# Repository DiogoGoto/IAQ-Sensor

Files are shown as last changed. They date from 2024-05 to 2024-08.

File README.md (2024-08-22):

# Indoor Air Quality (IAQ) Sensor

## Project Description
Low-cost indoor air quality sensor, this sensor is capable of collecting various air quality parameters and sending this data to a database hosted by Microsoft Azure, where the data can be accessed by a website. This data is also broadcasted using Bluetooth and it can be collected using an app developed using MIT App Inventor, with this app, and multiple sensors, it is also possible to keep track of where an individual has been and collect the personal air quality. More info at [Project post](https://www.hackster.io/Diterragames/indoor-air-quality-sensors-iaq-27ae14#overview)

## Table of Contents
- [Project Description](#project-description)
- [Functionality](#functionality)
- [Components](#components)
- [Quick Setup](#quick-setup)
- [Libraries](#libraries)
- [Contact](#contact)

## Functionality
- Measures Temperature (Celsius)
- Measures Relative Humidity (%)
- Measures CO2 (PPM)
- Measures Pressure (hPa) 
- Measures VOCs (PPM)
- Measures PM 1.0, 2.5, 10 (ug/m3)
- Sends data through Bluetooth
- Sends data to an online database
- Website to visualize the data

## Components
- [ESP-32 S3 Reverse TFT Feather](https://learn.adafruit.com/esp32-s3-reverse-tft-feather/overview)
- [ESP-32 S2 TFT Feather](https://learn.adafruit.com/adafruit-esp32-s2-tft-feather/overview)
- [SCD 30](https://learn.adafruit.com/adafruit-scd30/overview)
- [PMSA0031](https://learn.adafruit.com/pmsa003i/overview)
- [BME688](https://learn.adafruit.com/adafruit-bme680-humidity-temperature-barometic-pressure-voc-gas/overview)
- [Stemma QT cable 100mm](https://www.adafruit.com/product/4210)
- [Lipo 1200mAh Battery](https://www.adafruit.com/product/258)

## Quick Setup
Start by cloning this repository into your machine
#### Case and Circuit
1. Print the enclosure files under CAD Files.
2. Solder the sensors to the perfboard.
3. Connect the components as shown in the schematic.
4. Put the components inside their cases.
#### Cloud
1. Create a resource
2. Create an Azure IoT device using symmetric key as authentication type.
3. Save the _Device ID_ and _Primary Key_.
4. Create a CosmosDB account.
5. Create a CosmosDB routing endpoint.
6. Install Python 3.9.
7. Inside the project folder, run the following command: pip install -r requirements.txt.
8. Open cosmosdb.py and add your endpoint, database name and container name.
9. Run server.py.
10. Open azure_client.html.
#### Communication Unit Code
1. Install the esp32 board manager on version 2.0.17 by Espressif.
2. Install the [libraries](#libraries) for the communication unit.
3. Copy the folder _Uofc_Iaq_Library_ located Communication Unit\iaqazure\lib into your Arduino Libraries folder.
4. Create a folder named _iaqwif_" in the Libraries folder, then copy the _IaqWifi.h_ from src folder, paste it into the new folder, and rename it to _iaqwifi.h_
5. Open Communication Unit\iaqazure\src\azure\iot_configs.h change the wifi and Microsoft Azure settings.
6. Open Communication Unit\iaqazure\iaqazure.ino and update the ID to match the ID in the sensor unit code.
7. Upload the Communication unit code to the ESP-32 **S2**.
#### Sensor Unit Code
1. Install the [libraries](#libraries) for the sensor unit.
2. Open the file iaq_sensor located in Sensor Unit\IAQ_Sensor_Unit_Code.
3. Make sure that _BLE_MODE_ = 2 and that each sensor has an unique _SENSOR_ID_.
4. Upload the Sensor unit code to the ESP-32 **S3**.
#### Mobile App
1. Import the project into [MIT App Inventor](https://ai2.appinventor.mit.edu/).
2. Export the apk or use the [MIT Companion App](https://play.google.com/store/apps/details?id=edu.mit.appinventor.aicompanion3) to open the app.
3. Allow any permission requests by the app.

More details on how to set up are available in this [post](https://www.hackster.io/Diterragames/indoor-air-quality-sensors-iaq-27ae14#overview) in hackster.io.

## Libraries
#### Sensor Unit Libraries
- SPI
- Wire
- Adafruit_Sensor
- Adafruit_GFX
- Adafruit_ST7789
- Adafruit_SCD30
- Adafruit_PM25AQI
- BME68x Library
- [Bosch BSEC 2](https://github.com/boschsensortec/Bosch-BSEC2-Library/tree/master)
- Hardware Serial
- BLE Device
- BLE Advertising
- Any dependencies for these libraries
#### Communication Unit Libraries
- Azure SDK for C	
- ArduinoJson  
- Any dependencies for these libraries

## Thanks
I want to thank Dr. Simon Li who sponsored us by providing the needed components and accompanied the entire progress of this project. Thanks to my partner, Dr. Sheng Li, for participating in this project and assisting me. Last but not least the University of Calgary Electrical Makerspace for supplying us with materials, and allowing us to use its spaces and equipment to bring this project to reality.

## Contact
diogo.goto@gmail.com

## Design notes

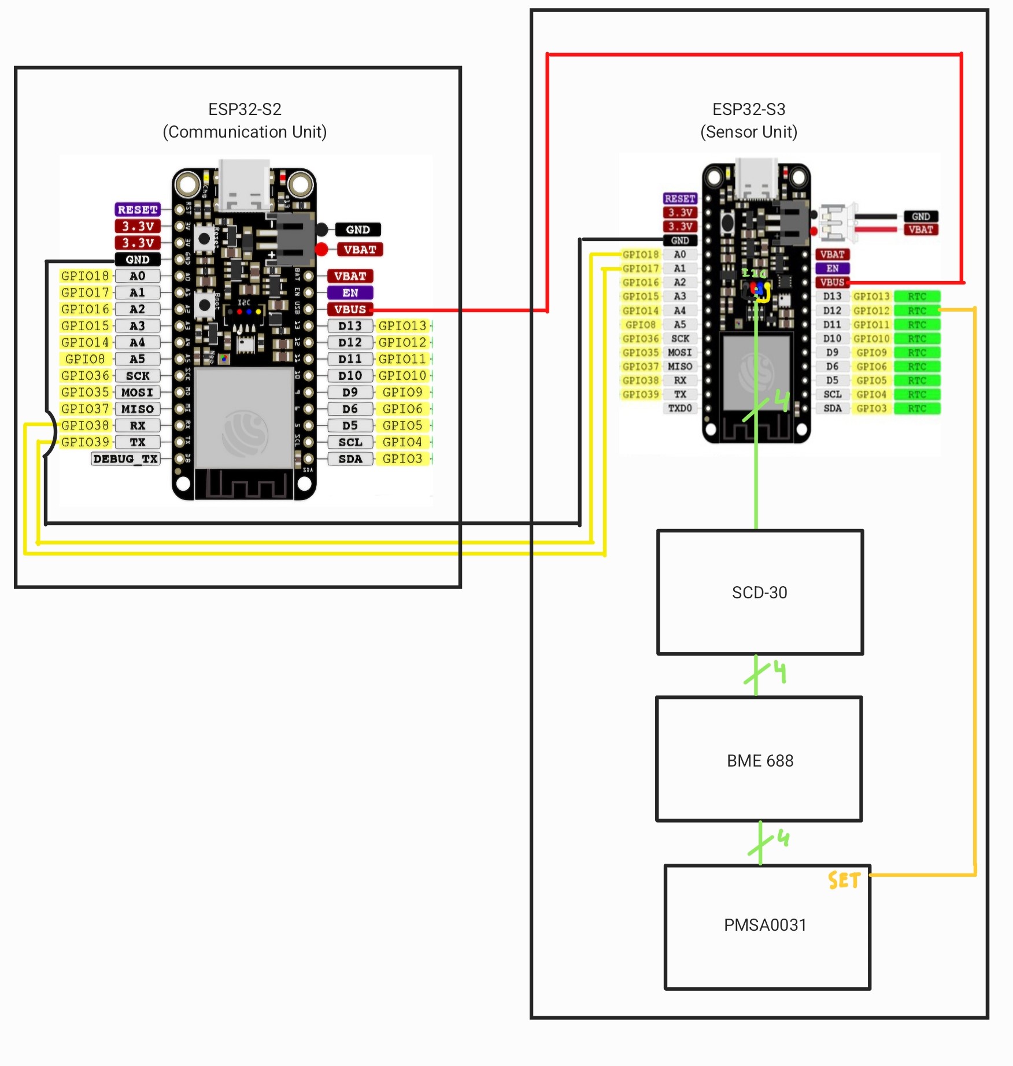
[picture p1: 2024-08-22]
Schematic.jpg

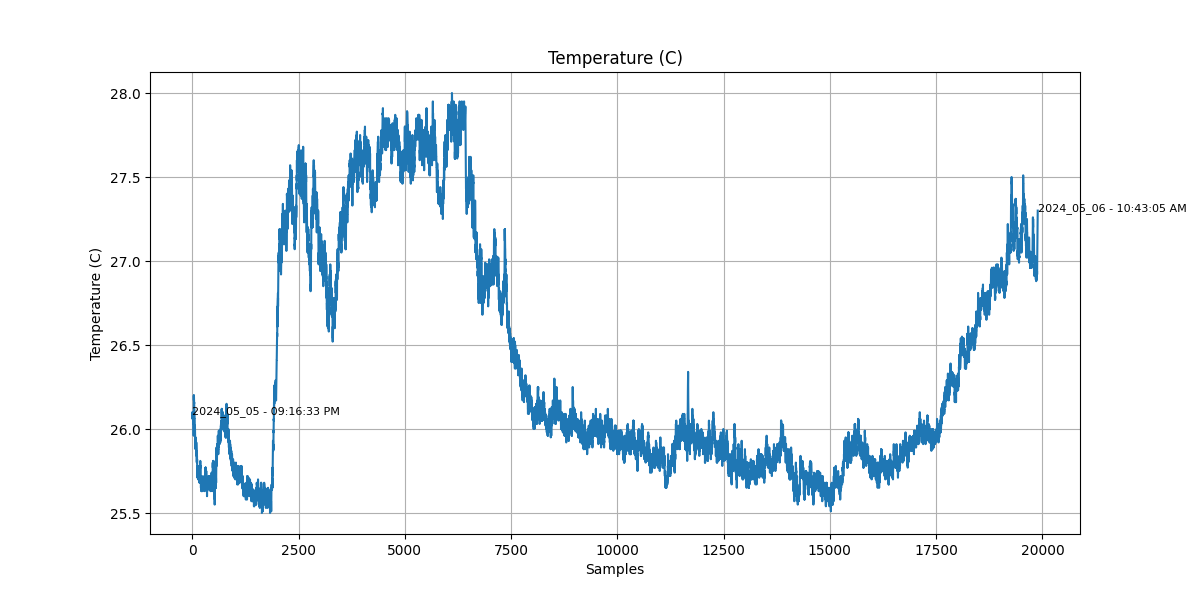
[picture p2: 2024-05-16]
Data_Logging/Graphs/Temp.png

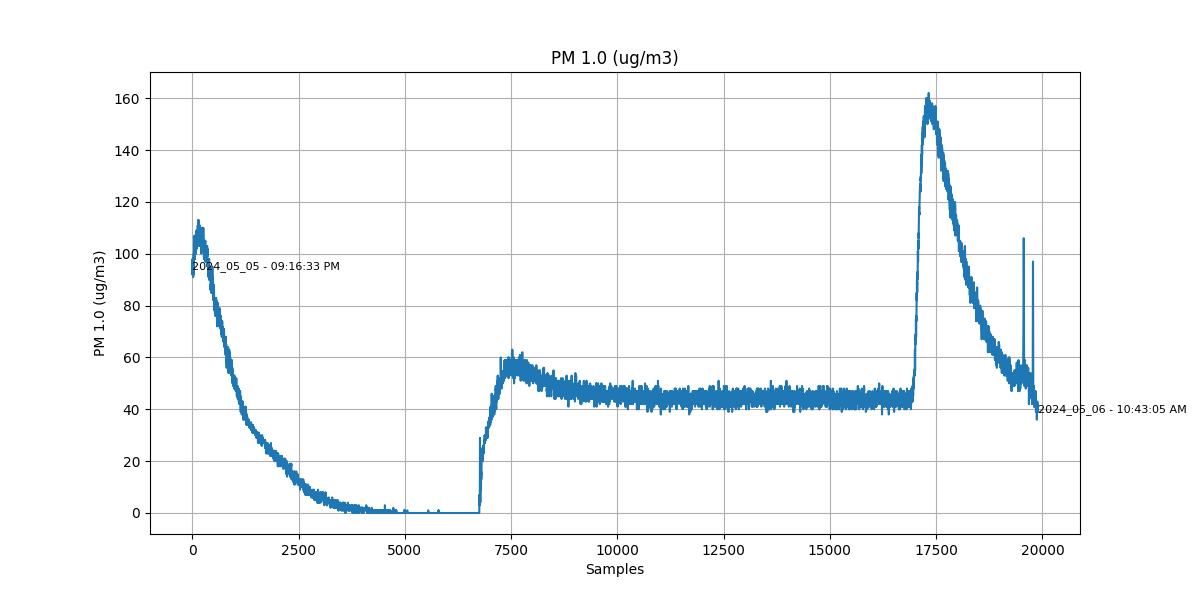
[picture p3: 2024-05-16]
Data_Logging/Graphs/PM1.png

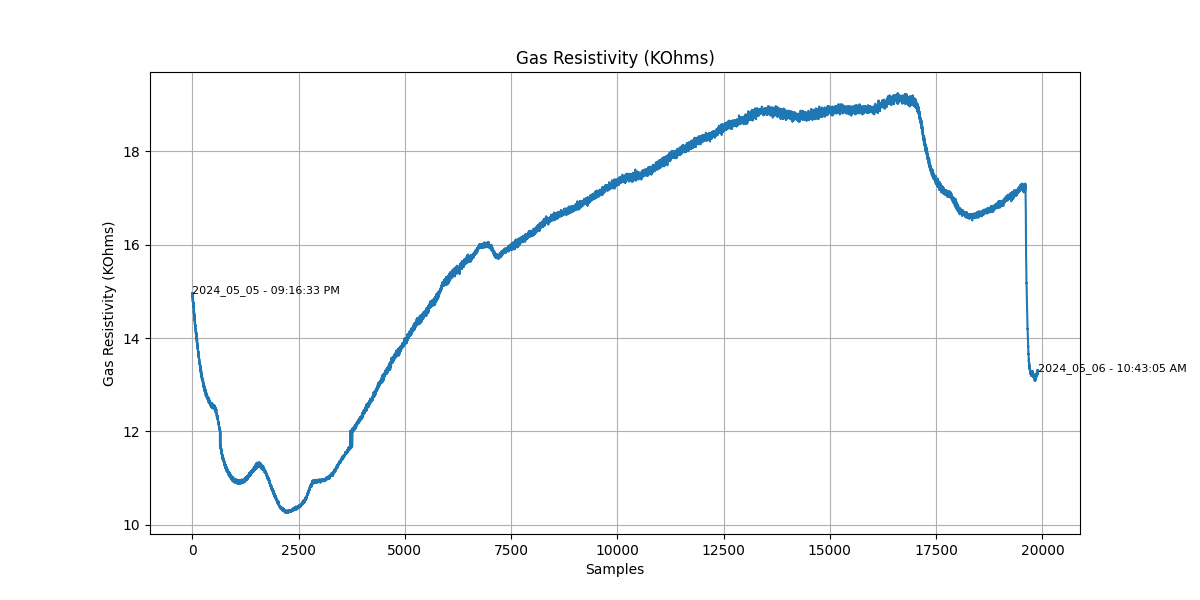
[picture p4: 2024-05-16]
Data_Logging/Graphs/Gas.png

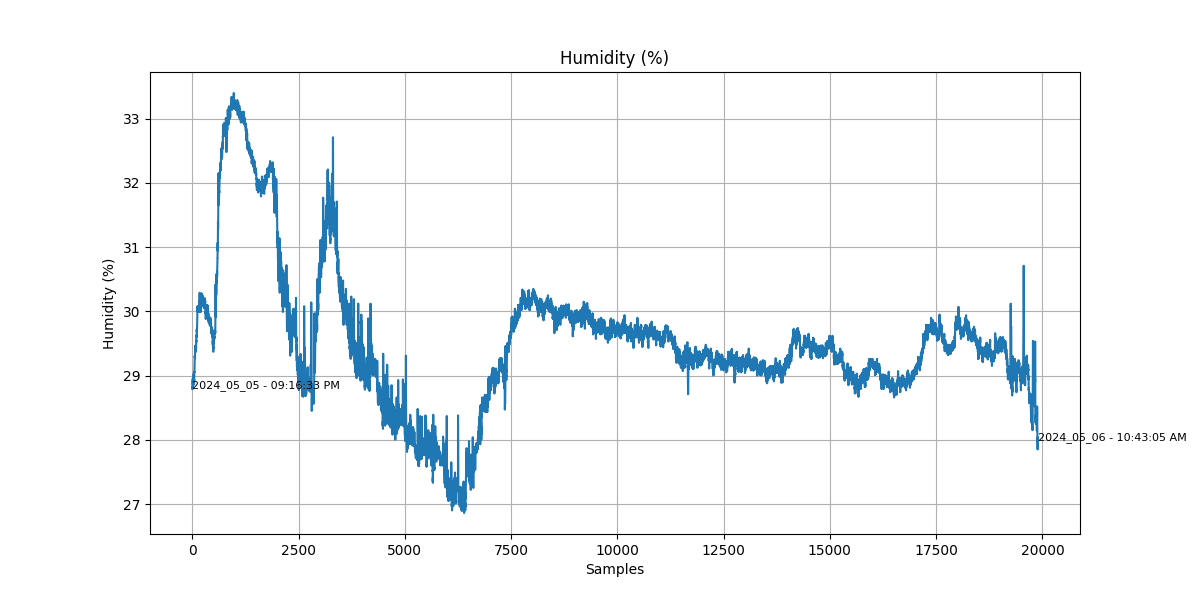
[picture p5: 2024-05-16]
Data_Logging/Graphs/RH.png

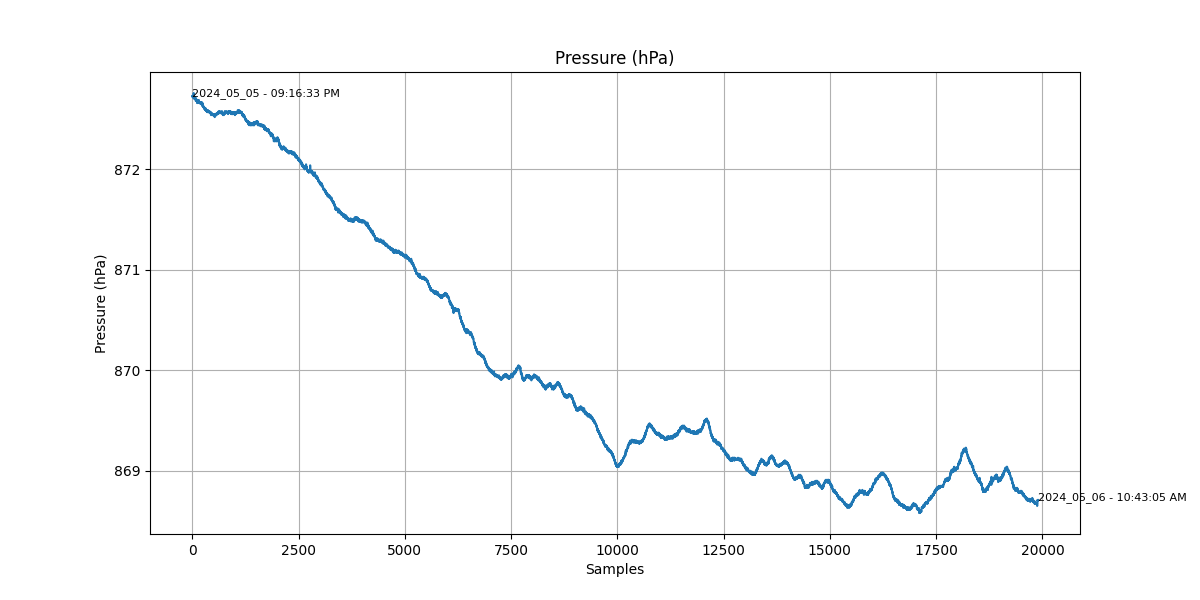
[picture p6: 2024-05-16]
Data_Logging/Graphs/Pres.png

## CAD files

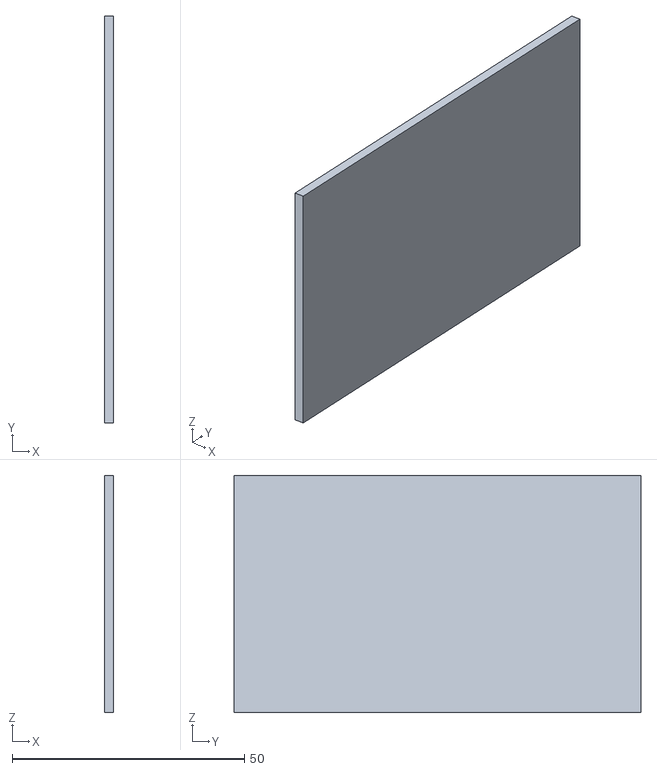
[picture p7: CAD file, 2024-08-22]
CAD Files/Cover Communication Unit.stl
2.00 x 87.5 x 51.0

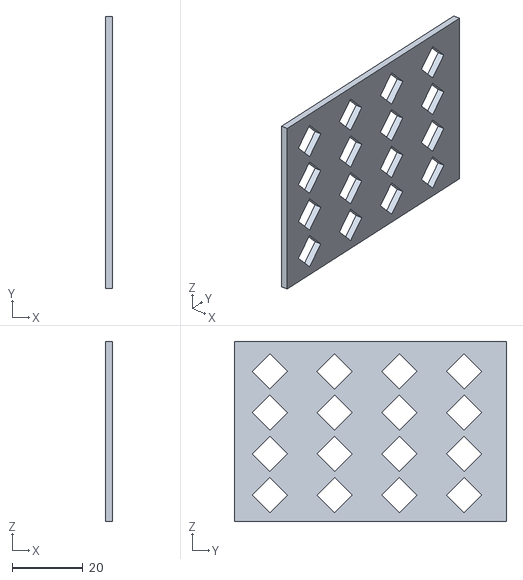
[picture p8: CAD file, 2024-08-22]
CAD Files/Cover Sensor Unit.stl
2.00 x 77.0 x 51.0

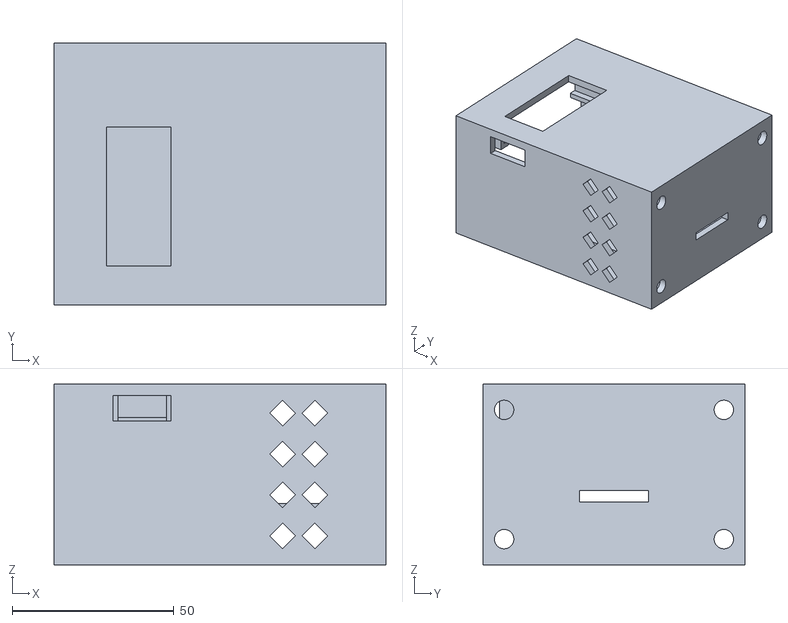
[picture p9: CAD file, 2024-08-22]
CAD Files/Case Sensor Unit.stl
102.8 x 81.0 x 56.0

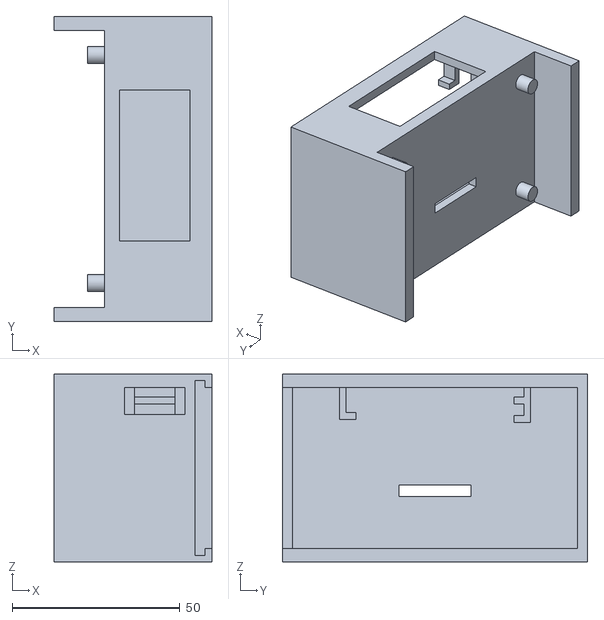
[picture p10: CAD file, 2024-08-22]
CAD Files/Case Communication Unit.stl
47.0 x 91.0 x 56.0

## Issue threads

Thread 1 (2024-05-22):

Design PCB

DiogoGoto, 2024-05-22:
- [ ] Design  and simulate Power Source Selector PCB
- [ ] Arrange Perf Board
- [ ] Design Interface with Dr. Sheng's Part

DiogoGoto, 2024-08-22:
Opted to use perf board and breakout boards, as designig a PCB was outside of the scope of the project

Closed 2024-08-22.

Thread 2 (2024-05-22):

Interface with Dr. Sheng's Part

DiogoGoto, 2024-05-22:
- [x] Decide Communication Protocol
- [x] Design physical connector
- [x] Decide formatting of the message (Modular Design)

DiogoGoto, 2024-08-22:
Implemented using Serial communication, the design of the connector was an 8-pin header, and the message was formatted to  "T=26.24,RH=28.83,P=886.46,CO2=496.52,VOC=0.58,PM1.0=0.00,PM2.5=0.00,PM10=0.00,[\n]". More info in post at hackster.io (link in README)

Closed 2024-08-22.

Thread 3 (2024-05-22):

Decide Size and Type of Battery

DiogoGoto, 2024-05-22:

DiogoGoto, 2024-08-22:
Opted for 1200mAh battery allowing for 8 hours of usage and connected directly into the ESP-32 S3 Battery Board. Check Schematic for more info.

Closed 2024-08-22.

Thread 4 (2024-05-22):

Check Power Consumption

DiogoGoto, 2024-05-22:
- [x] Check No Sleep mode
- [x] Check Modern Sleep
- [x] Check Light run mode
- [x] Check for Deep Sleep mode
- [x] Check Hibernate
-

DiogoGoto, 2024-08-22:
Opted for no sleep due to not being able to power off the BME680 and getting a reading right after being powered on. However, still turning off the PMSA0031 when not needed, and increasing the sampling interval to every minute, which allows a battery life of ~8 hours

Closed 2024-08-22.

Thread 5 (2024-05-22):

Implement Solar Panels

DiogoGoto, 2024-05-22:
- [x] Look For Solar Panels
- [ ] Create V x Light Intensity Curve, I x Light Intensity Curve
- [ ] Design Regulator Based on the Curves

DiogoGoto, 2024-08-22:
Requires a battery and solar panel too big to be worth

Closed 2024-08-22.

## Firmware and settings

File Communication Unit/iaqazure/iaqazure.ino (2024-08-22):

#define PART_IOT 1 // 0=sensor; 1=iot; Leave this line as is
#define PART_ID 1 // change here for each device
#define IAQ_AZURE_IOT_ID PART_ID 

#include <Wire.h>
#include <SPI.h>

#include <Adafruit_GFX.h>
#include <Adafruit_ST7789.h>
Adafruit_ST7789 tft = Adafruit_ST7789(TFT_CS, TFT_DC, TFT_RST);

// --- network;
#include "src/IaqWifi.h"
//#include "iaqaws.h"
#include "src/azure/azure.h"
#include "src/iaqnettime.h"

IaqWifi* iaqwifi = new IaqWifi();
IaqNettime iaqnettime = IaqNettime();
//IaqAws iaqaws = IaqAws();
Azure* iaqiot= new Azure();
#include <ArduinoJson.h>

// --- sensor modules;
#if PART_IOT ==1
#include <Adafruit_Sensor.h>
#include <IaqCo2.h>
//#include <IaqBme680.h>
//#include <iaqbme68x.h>
#include "src/iaqbsec.h"  // BME688
//#include <iaqSGP40.h>
#include <IaqPm.h>

IaqCo2 *iaqco2 = new IaqCo2();
IaqPm *iaqpm = new IaqPm();
IaqBsec* iaqbme = new IaqBsec();
//IaqBme68x* iaqbme = new IaqBme68x();
//IaqBme680 *iaqbme = new IaqBme680();
//IaqSGP40* iaqsgp = new IaqSGP40();
#endif

struct Iaqdata
{
  float sensorid = PART_ID;
  float temperature = 0.0;
  float humidity = 0.0;
  float pressure = 0.0;
  float gasResistance = 0.0;
  float gasiaq=0.0;
  float gasevoc=0.0;
  float gaseco2=0.0;
  float co2conc = 0.0;
  float pm2dot5 = 0.0;
  float pm1_0 = 0.0;
  float pm10 = 0.0;

  long long int timestamp = 0;
  long long int date = 0;

}iaqdata;
char jsonBuffer[512];

// --- other variables;
unsigned long last_time = millis();


void setup()
{
  delay(100);
  Serial.begin(115200);
  Serial1.begin(9600);
  Interface.begin(9600, SERIAL_8N1, RXD2, TXD2);
  delay(5000);

  Serial.println("--- iaq azure setup---");
  //iaqaws.setup();
  iaqiot->iaqwifi = iaqwifi;
  iaqiot->setup();
  iaqnettime.setup();

  setuptft();

#if PART_IOT==0
  iaqco2->setup();
  iaqpm->setup();
  iaqbme->setup();
  //bme_setup();
  //iaqsgp->setup();
#endif

}

bool isok=false;
int delaytime=300;
int iottime=50*1000/delaytime; // *100ms;
int iotcnt=iottime;   // for send data to iot server;
int readtime=3*1000/delaytime; // 2s;
int readcnt=readtime;
//int cnt=iotcnt-2000/delaytime;

unsigned char msgid=0;
bool isdata = false;

void loop() 
{
  isok = false;

  // if(iotcnt++>=iottime)
  // {
  //   iotcnt=0;
  //   //iaqaws.connectAWS();
  //   iaqwifi->connectToWiFi();
  //   //iaqiot->loop();
    
  //   if(iaqnettime.setup()){
  //     iaqdata.timestamp = iaqnettime.printLocalTime(); // Get the current timestamp
  //     iaqdata.date = iaqnettime.printLocalDate();
  //   }
  // }

#if PART_IOT==0
  iaqbme->read();

  if(readcnt++ >= readtime)
  {
    readcnt = 0;

    if(!iaqco2->read()) isok = false;
    iaqpm->read();
    //bme_read();

    //temperature = round((iaqco2->scd30.temperature -3.5)* 100) / 100;
    iaqdata.temperature = iaqbme->bme.temperature;
    iaqdata.humidity = iaqbme->bme.humidity;//round(iaqbme->bme.humidity * 100) / 100;  // %
    iaqdata.pressure = iaqbme->bme.pressure/100.0;//round((iaqbme->bme.pressure / 100.0) * 100) / 100; // Convert pressure to hPa
    iaqdata.gasResistance = iaqbme->bme.gas_resistance/1000.0;//round((iaqbme->bme.gas_resistance / 1000.0) * 100) / 100; // Convert gas resistance to kOhms
    iaqdata.gaseco2 = iaqbme->bme.eco2;
    iaqdata.gasevoc = iaqbme->bme.evoc;
    iaqdata.gasiaq = iaqbme->bme.iaq;

    iaqdata.co2conc = round(iaqco2->scd30.CO2 * 100) / 100;
    iaqdata.pm2dot5 = iaqpm->data.pm25_standard;
    iaqdata.pm1_0 = iaqpm->data.pm10_standard;
    iaqdata.pm10 = iaqpm->data.pm100_standard;

    sendSerial(&Serial);
    sendSerial(&Serial1);

    tft.fillScreen(ST77XX_BLACK); // Clear the TFT screen
    tft.setCursor(0, 0);
    tft.setTextSize(2);
    tft.setTextColor(ST77XX_GREEN);
    showTft();

    isdata = true;
  }
#else   // iot part;
  // receive data from serial port 1;
  if(receiveSensor(&Serial1)||receiveSensor(&Interface)) 
  {
    isdata = true;

    //sendSerial(&Serial);

    tft.fillScreen(ST77XX_BLACK); // Clear the TFT screen
    tft.setCursor(0, 0);
    tft.setTextSize(2);
    tft.setTextColor(ST77XX_GREEN);
    showTft();
    last_time = millis();
  }
  if(millis() - last_time > 65000){//Does not receive a message in the last 65 seconds
    tft.fillScreen(ST77XX_BLACK); // Clear the TFT screen
    tft.setCursor(0, 0);
    tft.setTextSize(3);
    tft.setTextColor(ST77XX_RED);
    tft.println("Disconnected");
    last_time = millis();
    Serial.print(millis()); Serial.print(last_time); Serial.println(millis() - last_time);
  }
#endif

  if(iotcnt++>=iottime && isdata)
  {
    isdata = false;

    iotcnt=0;
    //iaqaws.connectAWS();
    iaqwifi->connectToWiFi();
    //iaqiot->loop();
    
    if(iaqnettime.setup()){
      iaqnettime.printLocalTimeStr();
      //iaqdata.timestamp = iaqnettime.printLocalTime(); // Get the current timestamp
      //iaqdata.date = iaqnettime.printLocalDate();
    }
    
    int d = setMsg(iaqdata.sensorid, iaqdata.temperature, iaqdata.humidity, iaqdata.pressure, 
       iaqdata.gasevoc,//iaqdata.gasResistance,
       iaqdata.co2conc,iaqdata.pm2dot5,
       msgid++,iaqnettime.timestr);
    iaqiot->loop(jsonBuffer, d);
  
    // iaqaws.publishMessage(iaqdata.sensorid, iaqdata.temperature, iaqdata.humidity, iaqdata.pressure, 
    //   iaqdata.gasResistance,iaqdata.co2conc,iaqdata.pm2dot5,
    //   iaqdata.timestamp,iaqdata.date);
  }

  delay(delaytime);
}


int setMsg(float sensorid, float temperature, float humidity, float pressure, 
        float gasResistance, float co2conc, float pm2dot5, unsigned char msg_id, const char* timestr)//long long int timestamp, long long int date)
{
    //if(!isconnected) return;

    StaticJsonDocument<200> doc;
    doc["id"] = sensorid;
    doc["msgid"] = msg_id; // Add timestamp (in milliseconds)
    doc["datetime"] = timestr;
    doc["T"] = temperature;
    doc["RH"] = humidity;
    doc["P"] = pressure;
    doc["eVOC"] = gasResistance;
    doc["CO2"] = co2conc;
    doc["PM25"] = pm2dot5;
    
    return serializeJson(doc, jsonBuffer);

    // client->publish(AWS_IOT_PUBLISH_TOPIC, jsonBuffer);
    // //Serial.println(client->connected());
    // client->loop();
    // //Serial.println(client->connected());
}
bool receiveSensor(Stream* sp)
{
  bool isall=false;
  String str;
  String s;
  int d;
  while(true)
  {
    if(sp->available())
    {
      str = sp->readStringUntil(','); // terminal char is discarded;
      try
      {
        d = str.indexOf('=');
        s = str.substring(0,d+1);
        str = str.substring(d+1); 
        float f = str.toFloat();
        //Serial.printf("%s=%.2f\n",str,f);

        if (s.equals("T="))          {iaqdata.temperature=f; Serial.printf("t=%.2f,", iaqdata.temperature);}
        else if (s.equals("RH="))    {iaqdata.humidity=f; Serial.printf("rh=%.2f,", iaqdata.humidity);}
        else if (s.equals("P="))     {iaqdata.pressure=f; Serial.printf("co2=%.2f,", iaqdata.pressure);}
        else if (s.equals("CO2="))   {iaqdata.co2conc=f; Serial.printf("co2=%.2f,", iaqdata.co2conc);}
        else if (s.equals("VOC="))   {iaqdata.gasevoc=f; Serial.printf("voc=%.2f,", iaqdata.gasevoc);}
        else if (s.equals("PM1.0=")) {iaqdata.pm1_0=f; Serial.printf("pm1.0=%.2f,", iaqdata.pm1_0);}
        else if (s.equals("PM2.5=")) {iaqdata.pm2dot5=f; Serial.printf("pm2.5=%.2f,", iaqdata.pm2dot5);}
        else if (s.equals("PM10="))  {iaqdata.pm10=f; Serial.printf("pm10=%.2f,\n", iaqdata.pm10); isall = true;}

      }
      catch(...)
      {
        Serial.println("convert error.");
      }
    }
    else
    {
      break;
    }
  }
  return isall;
}
void sendSerial(Stream* sp)
{
  sp->printf("T=%.2f,", iaqdata.temperature);
  sp->printf("RH=%.2f,", iaqdata.humidity);
  sp->printf("P=%.2f,", iaqdata.pressure);
  sp->printf("CO2=%.2f,", iaqdata.co2conc);
  sp->printf("VOC=%.2f,", iaqdata.gasevoc);
  sp->printf("PM1.0=%.2f,", iaqdata.pm1_0);
  sp->printf("PM2.5=%.2f,", iaqdata.pm2dot5);
  sp->printf("PM10=%.2f,", iaqdata.pm10);
  sp->println();
  // sp->print("T: ");  Serial.print(iaqdata.temperature); Serial.print(" °C");
  // Serial.print(", RH: ");  Serial.print(iaqdata.humidity); Serial.print(" %");
  // Serial.print(", P: ");  Serial.print(iaqdata.humidity); Serial.print(" hPa");
  // Serial.print(", IAQ: ");  Serial.print(iaqdata.gasiaq);
  // Serial.print(", eCO2: "); Serial.print(iaqdata.gaseco2);
  // Serial.print(", eVOC: "); Serial.print(iaqdata.gasevoc);
  // Serial.print(", R: "); Serial.print(iaqdata.gasResistance); Serial.println(" kOhms: ");
}

void showTft()
{
  tft.fillScreen(ST77XX_BLACK); // Clear the TFT screen
  tft.setCursor(0, 0);
  tft.setTextSize(2);
  tft.setTextColor(ST77XX_GREEN);

  //tft.print("T    : ");  tft.print(temperature - 3.5);  tft.println(" DegreeC");
  tft.print("T    : ");  tft.print(iaqdata.temperature);  tft.println(" *C");
  tft.print("P    : ");  tft.print(iaqdata.pressure);  tft.println(" hPa");
  tft.print("RH   : ");  tft.print(iaqdata.humidity);  tft.println("%");
  
  tft.print("PM2.5: ");  tft.print(iaqdata.pm2dot5);  tft.println("  units");
  tft.print("CO2  : ");  tft.print(iaqdata.co2conc);  tft.println("  ppm");
  tft.print("eCO2 : ");  tft.print(iaqdata.gaseco2);   tft.println("  ppm");
  tft.print("eVOC : ");  tft.print(iaqdata.gasevoc);  tft.println("   ppm");
  tft.print("IAQ  : ");  tft.println(iaqdata.gasiaq);

  // tft.print("SGP  : ");  tft.print(iaqsgp->raw/1000.0); tft.println(" kOhms");
  // tft.print("Index: ");  tft.println(gasiaq);
  //tft.print("VOC = "); tft.print(gasvoc);  tft.println(" ppm");
  //tft.print("Altitude = ");
  //tft.print(iaqbme->bme.readAltitude(SEALEVELPRESSURE_HPA));
}


void setuptft(void) {
  Serial.print(F("Hello! Feather TFT Test"));

  // turn on backlite
  pinMode(TFT_BACKLITE, OUTPUT);
  digitalWrite(TFT_BACKLITE, HIGH);

  // turn on the TFT / I2C power supply
  pinMode(TFT_I2C_POWER, OUTPUT);
  digitalWrite(TFT_I2C_POWER, HIGH);
  delay(10);

  // initialize TFT
  tft.init(135, 240); // Init ST7789 240x135
  tft.setRotation(3);
  tft.fillScreen(ST77XX_BLACK);
  tft.fillScreen(ST77XX_BLACK);
  tft.setCursor(0,0);
  tft.setTextSize(2);
  tft.setTextColor(ST77XX_GREEN);
}

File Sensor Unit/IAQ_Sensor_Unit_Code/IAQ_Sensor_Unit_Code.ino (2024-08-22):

#include "iaq_sensor.h" 
/* Includes all relevant libries
*  Create all definitions
*  Declare all structures
*/
#if BLE_MODE == 1
  std::string SENSOR_NAME = "IAQ_Sensor_X"; //Change here for each sensor if running in BLE_MODE 1
#endif


// Function Prototypes
//----------------------------------------------
void displayInit(); // Initializes Built-in Display
void SCD30Init(); // Initializes CO2 Sensor
void PMInit(); // Initializes PM Sensor
void BMEInit(); //Initializes VOC and Pressure Sensor
void prepWrite(uint8_t size, uint16_t color); // Sets cursor at 0,0 configures color and font size
void intro(); //shows the intro to the sensor
void showTft(); // Print data on the display
void sendSerial();// Print data on Serial
void sendInterface(); //Send data to Dr. Sheng's Part through Serial
void sendBLE(); //Sends data to Mobile Devices

#if BLE_MODE == 1
  int getConnectedDevicesCount(); //return how many clients are connected
  int getFreeClientSlot(); //Finds a slot for to connect a new device
  int getClientSlotByConnId(uint16_t conn_id); //finds client by their connection ID
#endif
// ---------------------------------------------


//Modules Initializations
//----------------------------------------------
Adafruit_ST7789 tft = Adafruit_ST7789(TFT_CS, TFT_DC, TFT_RST); // Display
Adafruit_SCD30  scd30; //CO2 Sensor
Adafruit_PM25AQI aqi = Adafruit_PM25AQI(); //PM Sensor
PM25_AQI_Data pmsa0031; //Data for the PM sensor
IaqBsec* iaqbme = new IaqBsec();// Pressure and VOC Sensor
HardwareSerial Interface(1); //Data Interface 
//----------------------------------------------

iaqData data_package; //Data collected by the sensors 
String message = ""; //String to send the IAQ data to the Communication unit
unsigned long  last_time = millis(); // Timer collect the data every minute

//BLE Variables
#if BLE_MODE == 1
  BLEServer* pServer = NULL;
  BLECharacteristic* pCharacteristic = NULL;
  DEVICE ble_devices[MAX_CONNECTIONS]; //initializes all variables to connect to multiple devices


  class MyServerCallbacks: public BLEServerCallbacks {
      void onConnect(BLEServer* pServer, esp_ble_gatts_cb_param_t *param) {
        int idx = getFreeClientSlot();
        if (idx != -1) {
              ble_devices[idx].conn_id = param->connect.conn_id;
              ble_devices[idx].status = true;
              Serial.printf("Device connected, connection ID: %d\n", param->connect.conn_id);
          }
        // Continue advertising if not at max connections
          if (getConnectedDevicesCount() < MAX_CONNECTIONS) {
              pServer->startAdvertising();
              Serial.println("Continuing to advertise.");
          }
      };

      void onDisconnect(BLEServer* pServer, esp_ble_gatts_cb_param_t *param) {
          int idx = getClientSlotByConnId(param->disconnect.conn_id);
          if (idx != -1) {
              ble_devices[idx].conn_id = 0;
              ble_devices[idx].status = false;
              Serial.printf("Device disconnected, connection ID: %d\n", param->disconnect.conn_id);
          }
          if (getConnectedDevicesCount() < MAX_CONNECTIONS) {
              pServer->startAdvertising();
              Serial.println("Device disconnected, starting advertising.");
          }
          
      }

  };
#endif

#if BLE_MODE == 2
  BLEMultiAdvertising advert(1); // max number of advertisement data 
  unsigned int last_ble = 0;
  String sdata = "";
  int ble_i = 0;
#endif

// MAIN CODE
//========================================================================
void setup() {
  // Initilization sequence
  Serial.begin(115200);
  Serial.println("Time, Temp, RH, Pres, CO2, Gas, PM1, PM25, PM10");
  displayInit();
  intro();
  prepWrite(2,WHITE);
  SCD30Init();
  PMInit();
  BMEInit();
  delay(500);
  Interface.begin(9600, SERIAL_8N1, RXD2, TXD2);


  //BLE Setup
  #if BLE_MODE == 1
    BLEDevice::init(SENSOR_NAME); // Create the BLE Device
    pServer = BLEDevice::createServer(); // Create the BLE Server
    pServer->setCallbacks(new MyServerCallbacks());
    BLEService *pService = pServer->createService(SERVICE_UUID);// Create the BLE Service
    
    // Create a BLE Characteristic
    pCharacteristic = pService->createCharacteristic(
                        CHARACTERISTIC_UUID1,
                        BLECharacteristic::PROPERTY_READ   |
                        BLECharacteristic::PROPERTY_WRITE  |
                        BLECharacteristic::PROPERTY_NOTIFY |
                        BLECharacteristic::PROPERTY_INDICATE
                      );

    //pCharacteristic->setCallbacks(new MyCharacteristicCallbacks());
    pCharacteristic->addDescriptor(new BLE2902());// Create a BLE Descriptor
    pService->start(); // Start the service

    // Start advertising
    BLEAdvertising *pAdvertising = BLEDevice::getAdvertising();
    pAdvertising->addServiceUUID(SERVICE_UUID);
    pAdvertising->setScanResponse(false);
    pAdvertising->setMinPreferred(0x0);  // set value to 0x00 to not advertise this parameter
    pServer->getAdvertising()->start();
    Serial.println("Waiting a client connection to notify...");
  #endif


  #if BLE_MODE == 2
    BLEDevice::init("");

    advert.setAdvertisingParams(0, &legacy_adv_params);
    advert.setAdvertisingData(0, sizeof(legacy_adv_data), &legacy_adv_data[0]);
    advert.setScanRspData(0, sizeof(legacy_scan_rsp_data), &legacy_scan_rsp_data[0]);
    advert.setInstanceAddress(0, addr_legacy);
    advert.setDuration(0);
    delay(1000);
    advert.start(1, 0); // Start advertising with instance count 1 and infinite duration 
  #endif
}
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

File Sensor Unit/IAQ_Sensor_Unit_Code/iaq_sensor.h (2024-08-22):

#ifndef IAQ_SENSOR_H
#define IAQ_SENSOR_H
#define BLE_MODE 2
// Includes
//-----------------------------------------------------------------------
#include <SPI.h>
#include <Wire.h>
#include <Adafruit_Sensor.h>
#include <Adafruit_GFX.h>     // Core graphics library
#include "Adafruit_ST7789.h"  // Hardware-specific library for ST7789
#include <Adafruit_SCD30.h>   // CO2 Sensor
#include <Adafruit_PM25AQI.h> // PM Sensor
#include <HardwareSerial.h>   // Inteface with Dr. Sheng's Part
#include "iaqbsec.h"          // VOC & Pressure Sensor 
//Bluetooth Low Energy  Librabries
#include <BLEDevice.h> 
#if BLE_MODE == 1
  #include <BLEServer.h>
  #include <BLEUtils.h>
  #include <BLE2902.h>
#endif
#if BLE_MODE == 2
  #include <BLEAdvertising.h>
#endif
#include <vector>
//-----------------------------------------------------------------------

// Definitions
//-----------------------------------------------------------------------
#define PMSA_SET 12
#define RXD2 18
#define TXD2 17

/*
#define TFT_I2C_POWER 21
#define TFT_CS 7
#define TFT_DC 39
#define TFT_RST 40
#define TFT_BACKLITE 45 
*/

#define SAMPLING_PERIOD 60000 // 1 minutes sampling period
#define SEALEVELPRESSURE_HPA (1013.25) // Constant 
#define MAX_CONNECTIONS 4
//-----------------------------------------------------------------------

// Bluetooth UUIDs
#define SERVICE_UUID         "4fafc201-1fb5-459e-8fcc-c5c9c331914b"
#define CHARACTERISTIC_UUID1 "beb5483e-36e1-4688-b7f5-ea07361b26a8"
#define CHARACTERISTIC_UUID2 "77376cda-d67f-4c80-981e-7f7cd032c684"
#define CHARACTERISTIC_UUID3 "3ea2d89f-5e58-454f-82ad-6fe705428db2"
#define CHARACTERISTIC_UUID4 "a0ea85f6-86ef-427b-8743-446f01fc3421"



// Colors definitions
// Colors are represented by 16bits values
//-----------------------------------------------------------------------
#define BLACK 0x0000
#define WHITE 0xFFFF
#define RED 0xF800
#define GREEN 0x07E0
#define BLUE 0x001F
#define CYAN 0x07FF
#define MAGENTA 0xF81F
#define YELLOW 0xFFE0
#define ORANGE 0xFC00
//-----------------------------------------------------------------------

typedef struct IAQ_DATA
{
  float sensorid = 3;
  
  //SCD 30 Data
  float temperature = 0.0;
  float humidity = 0.0;
  float co2 = 0.0;

  //PMSA 0031 Data
  float pm1dot0 = 0.0;
  float pm2dot5 = 0.0;
  float pm10 = 0.0;

  //BME 688 Data
  float gasTemperature = 0.0;
  float gasPressure = 0.0;
  float gasHumidity = 0.0;
  float gasResistance = 0.0;
  float gasIaq=0.0;
  float gaseVoc=0.0;
  float gaseCo2=0.0;
}iaqData;

#if BLE_MODE == 1
  typedef struct BLE_DEVICE
  {
    uint8_t id = 0;
    BLEClient* client = NULL;
    bool status = false;
    uint16_t conn_id = -1;
    std::string receivedString = "";
  }DEVICE;
#endif

#if BLE_MODE == 2
  #define  BLE_INTERVAL 5000
  #define SENSOR_ID '3'
  esp_ble_gap_ext_adv_params_t legacy_adv_params = {
      .type = ESP_BLE_GAP_SET_EXT_ADV_PROP_LEGACY_IND,
      .interval_min = 800,
      .interval_max = 800,
      .channel_map = ADV_CHNL_ALL,
      .own_addr_type = BLE_ADDR_TYPE_RANDOM,
      .filter_policy = ADV_FILTER_ALLOW_SCAN_ANY_CON_ANY,
      .primary_phy = ESP_BLE_GAP_PHY_1M,
      .max_skip = 0,
      .secondary_phy = ESP_BLE_GAP_PHY_1M,
      .sid = 2,
      .scan_req_notif = false,
  };

  static uint8_t legacy_adv_data[] = {
          0x02, 0x01, 0x06, //Flags
          0x02, 0x0a, 0xeb, //Tx Power
          22, 0x09,       //Complete Local Name
          'I', 'A', 'Q', '_', 'S', 'e', 'n', 's', 'o', 'r', '_', SENSOR_ID, ';', //[20]
          '0', '0', '0', '0', '0', '0', '0', 0X0
  };

  static uint8_t legacy_scan_rsp_data[] = {
          22, 0x09,                                    // 6-7
          'I', 'A', 'Q', '_', 'S', 'e', 'n', 's', 'o', 'r', '_', SENSOR_ID, ';', //[20]
          '0', '0', '0', '0', '0', '0', '0', 0X0
  };

  uint8_t addr_legacy[6] = {0xc0, 0xde, 0x52, 0x00, 0x00, 0x03};


#endif

#endif

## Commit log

2024-05-06 Add files via upload
    First Version of the IAQ Sensor
    Features
    - Temperature
    - Relative Humidity
    - CO2 Concentration
    - PM 1.0
    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
2024-05-16 New Sensors added, Small Energy efficiency improvements and code for data logging using python
    [Sensor_data.csv]
2024-08-22 Latest Version
    This contains all the information to fully recreate the IAQ system developed with the assistance of Dr. Sheng Li, and Dr. Simon Li.
    [Case Communication Unit.stl, Case Sensor Unit.stl, Cover Communication Unit.stl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]
2025-02-25 Bug fixes, i2c implemented
    needs testings
